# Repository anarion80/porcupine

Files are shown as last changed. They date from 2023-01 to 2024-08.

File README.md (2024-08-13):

# Porcupine 






Porcupine is an autogenerated, ergonomic, split, 36-42 key, wired/wireless, columnar-staggered keyboard. It is designed to fit my needs and my hand, but it can be easily updated thanks to declarative design.
It uses a ProMicro-compatible MCU board and supports both [QMK](https://qmk.fm/) and [ZMK](https://zmk.dev/) firmwares.

It is inspired by:

* [[Ferris] Sweep](https://github.com/davidphilipbarr/Sweep) keyboard
* [rae-dux](https://github.com/andrewjrae/rae-dux) keyboard
* [samoklava](https://github.com/soundmonster/samoklava) and its workflow
* all the work done by [Ben Vallack](https://github.com/benvallack) on his [Youtube channel](https://www.youtube.com/c/BenVallack)

It is fully Open-Source: the KiCad files are released under the solderpad license, version 2.1. The software (scripts/config files) in this repository is released under the GPL.

## :sparkles: Features

* Autogenerated - PCB layout is declared using YAML config files and generated into PCB files using [Ergogen](https://github.com/ergogen/ergogen) tool (migrated to V4).
Use [my fork](https://github.com/anarion80/ergogen) of it for added footprints.
* 3 variants:
  * regular 5x3 column-staggered ortholiner layout with 3 thumb keys (36 keys total)
  * regular 5x3 column-staggered ortholiner layout with 4 thumb keys (38 keys total)
  * regular 6x3 column-staggered ortholiner layout with 4 thumb keys (42 keys total)
* Wired or wireless
* Low-profile (using [Kailh Choc](http://www.kailh.com/en/Products/Ks/CS/) switches)
* Reversible PCB (save cost in production)
* Pro-micro/Elite C/Proton C/[nice!nano](https://nicekeyboards.com/nice-nano/) support
* Hot-Swap support
* SplitKB Tenting puck support.
* uses [KiKit](https://github.com/yaqwsx/KiKit) to render PCB previews (see below)
* uses [KiBot](https://github.com/INTI-CMNB/KiBot) to run DRC, create Gerber and Drill files for production (and Interactive BOM and 3d renders just for fun)

Front/Left | Back/Right
-|-
Porcupine
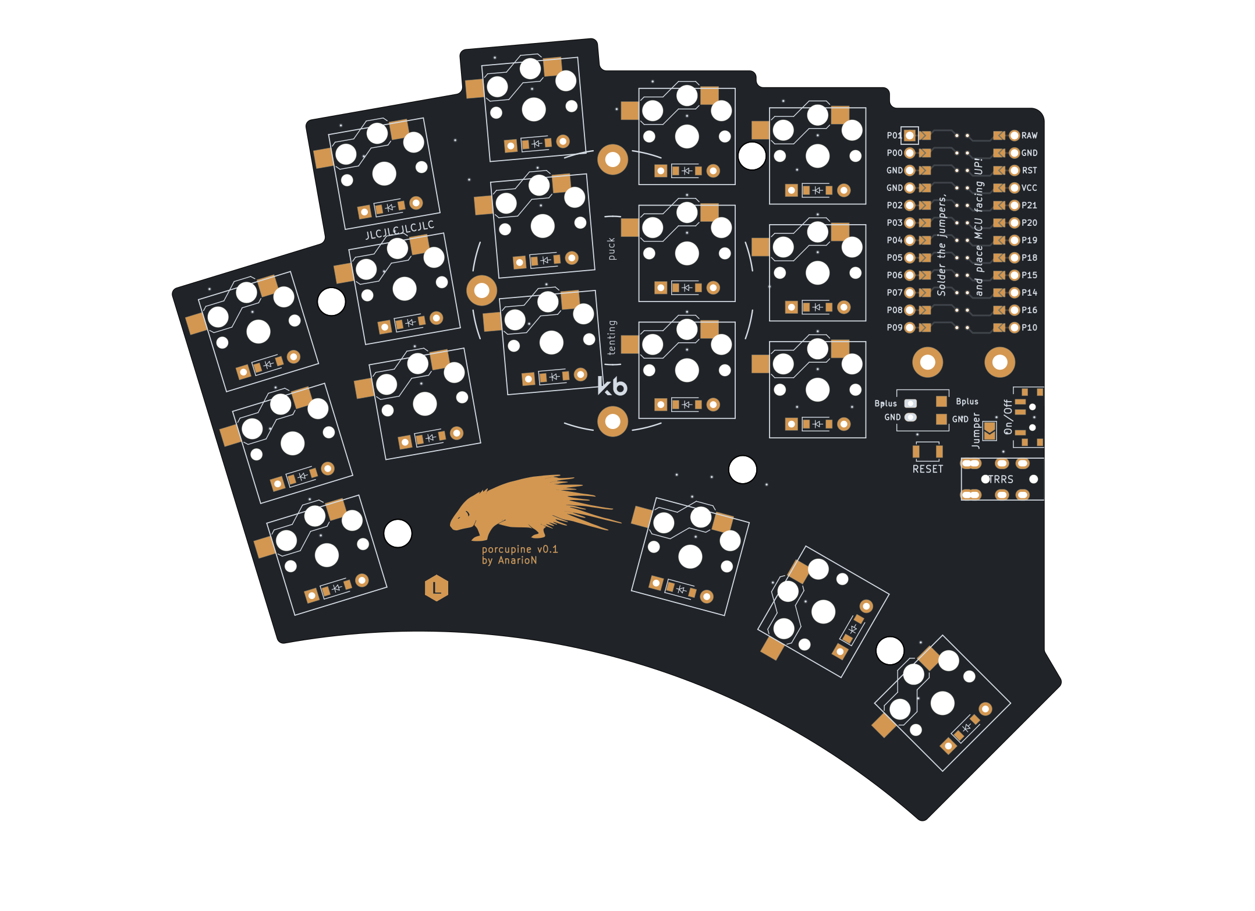
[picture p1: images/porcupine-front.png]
Porcupine Front
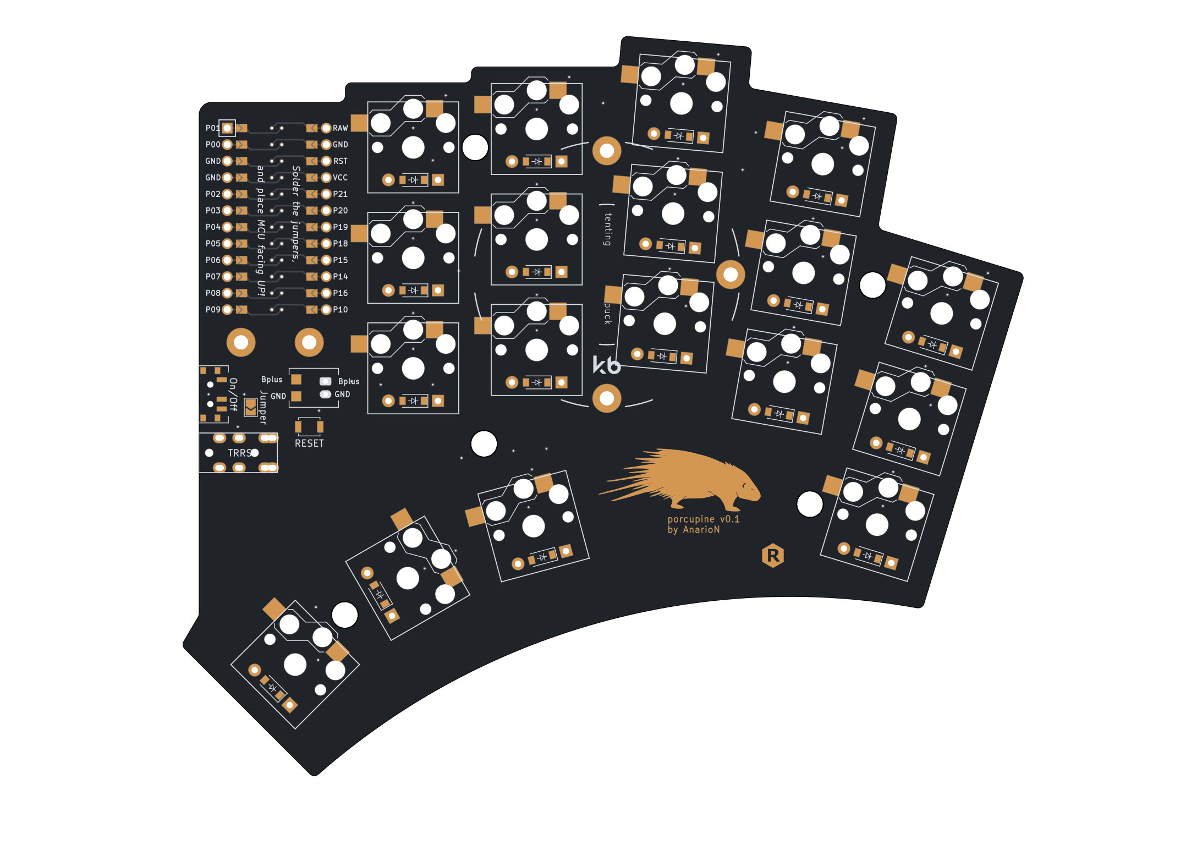
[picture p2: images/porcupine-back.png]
Porcupine Back
 | 
Porcupine 4 thumb keys
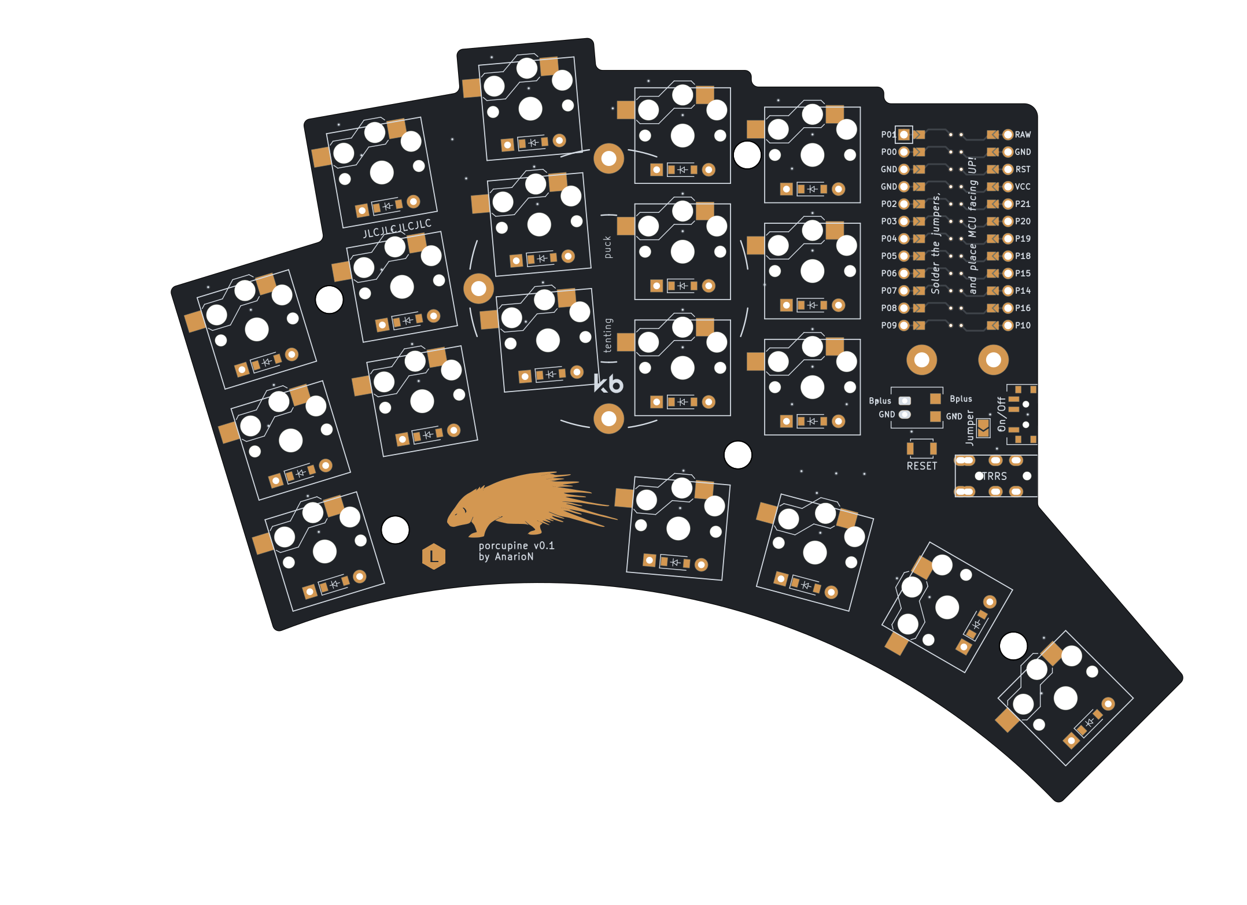
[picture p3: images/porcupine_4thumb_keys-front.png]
Porcupine Front
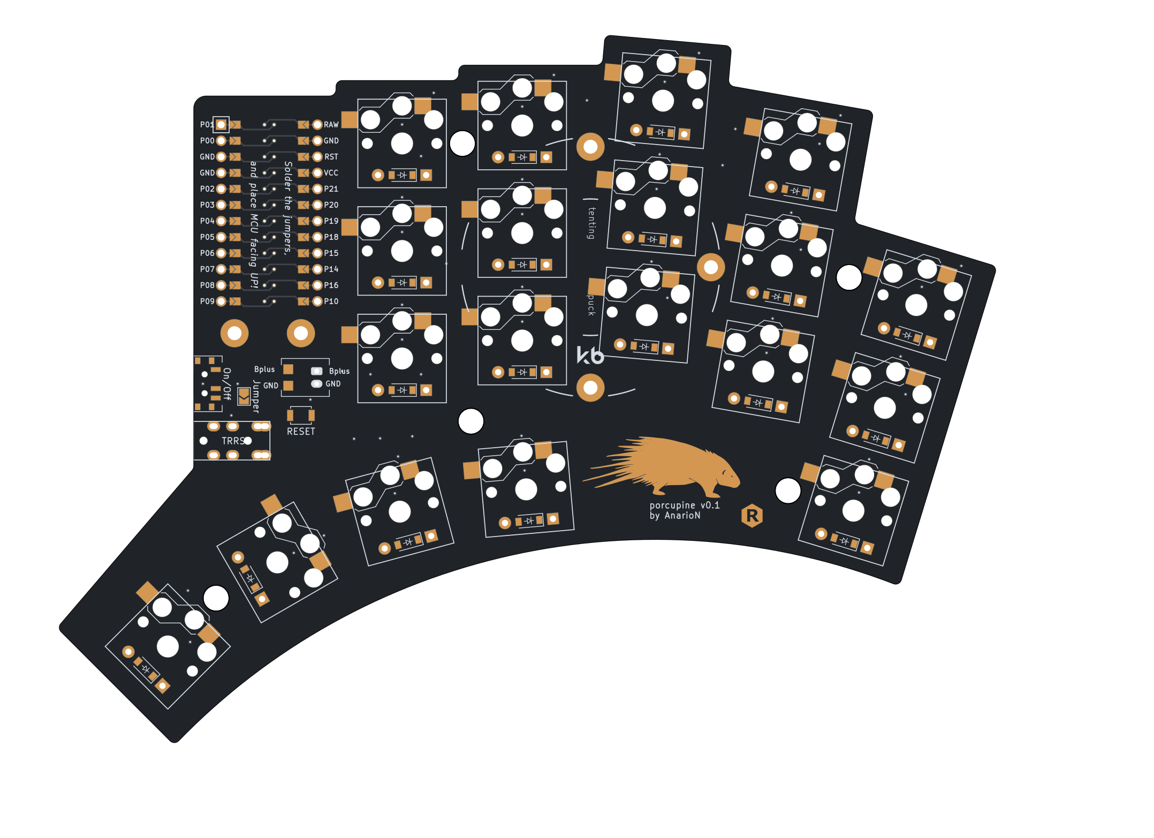
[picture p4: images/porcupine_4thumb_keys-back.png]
Porcupine Back
 | 
Porcupine 3x6
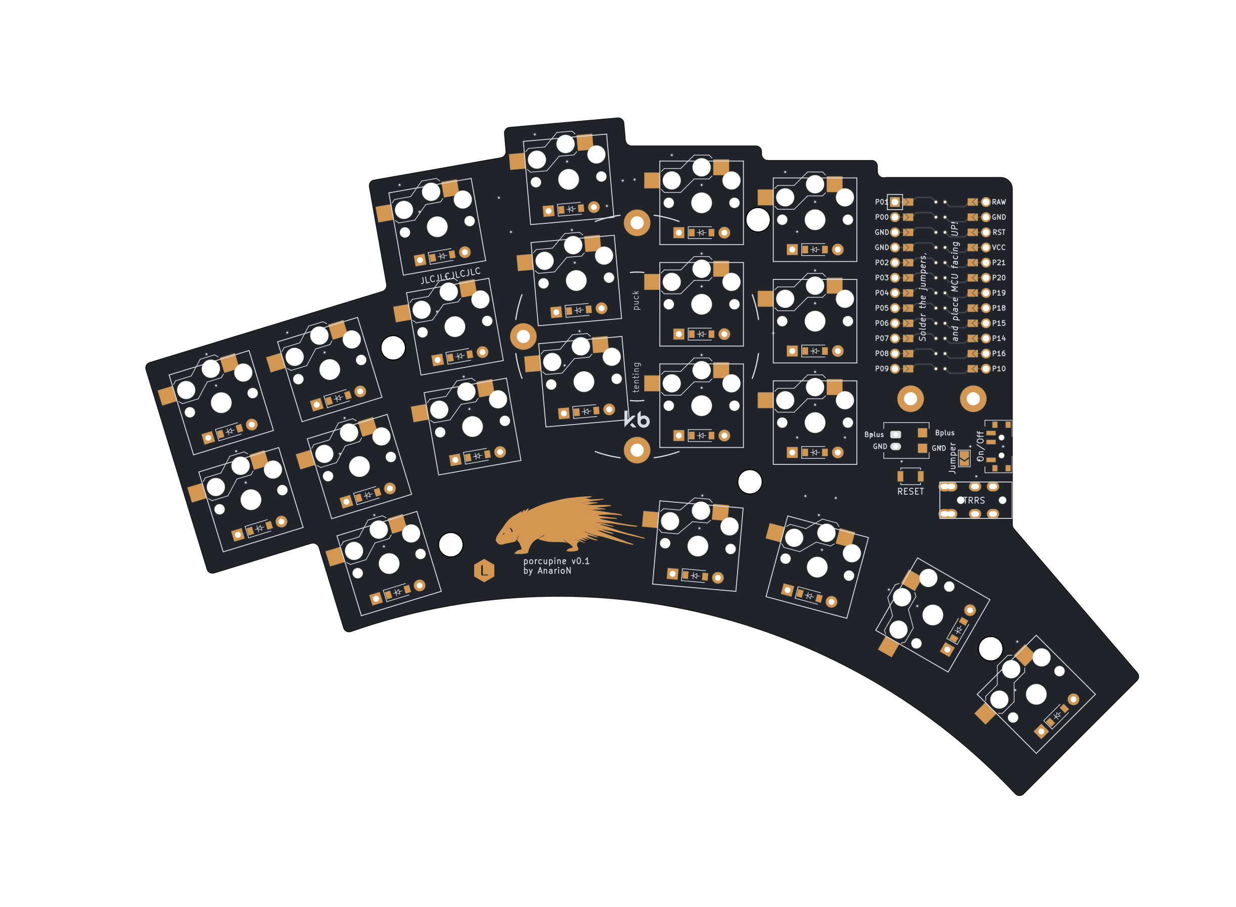
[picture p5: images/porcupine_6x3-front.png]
Porcupine Front
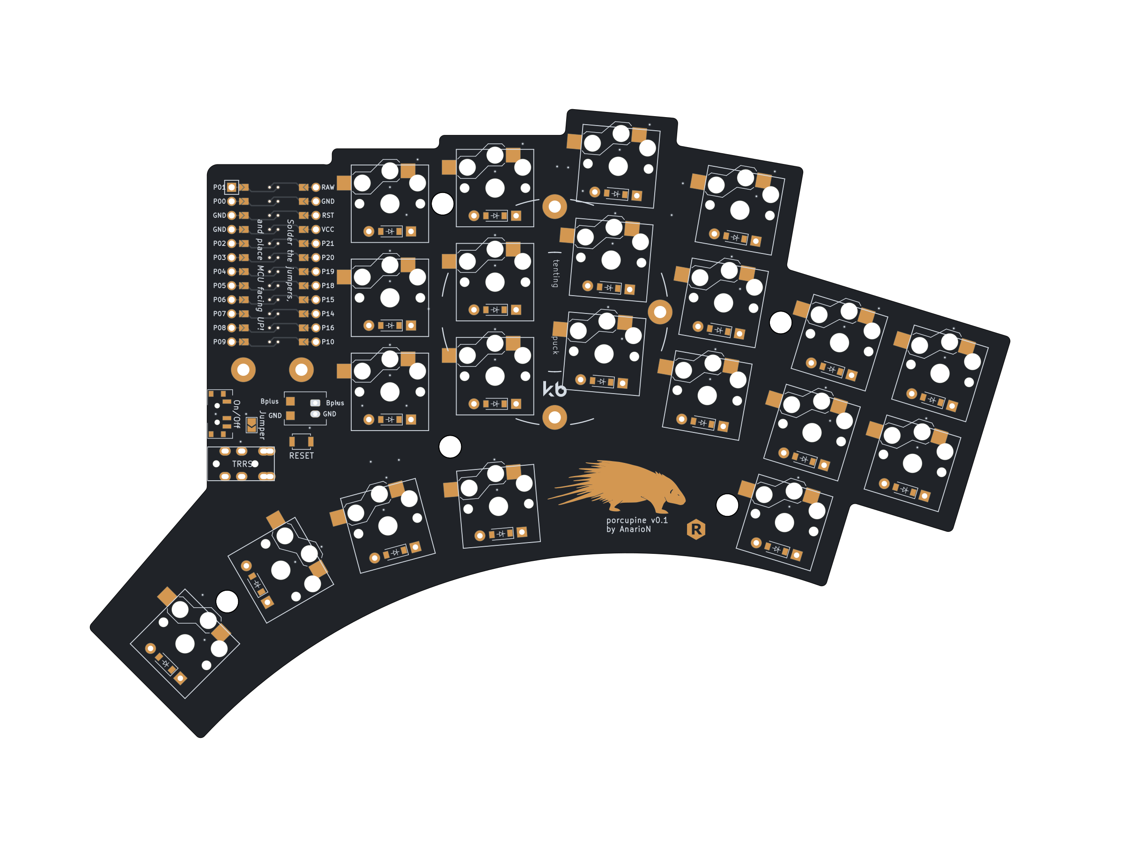
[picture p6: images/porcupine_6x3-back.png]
Porcupine Back
 | 
Prototype boards (generated using Ergogen v3 still):
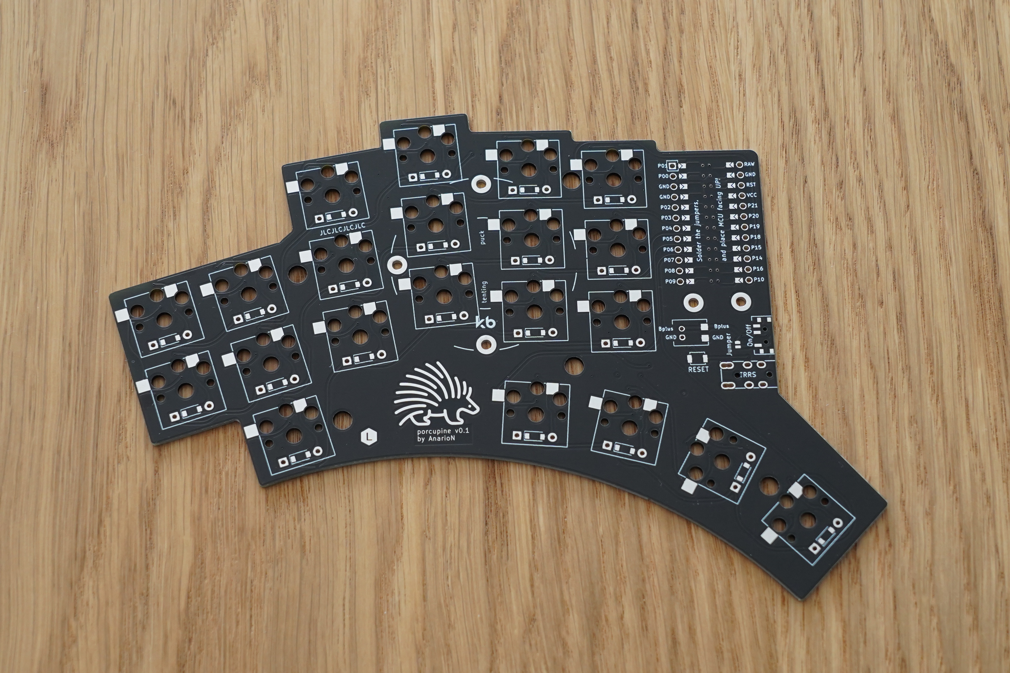
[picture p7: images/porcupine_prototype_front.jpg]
Porcupine Front
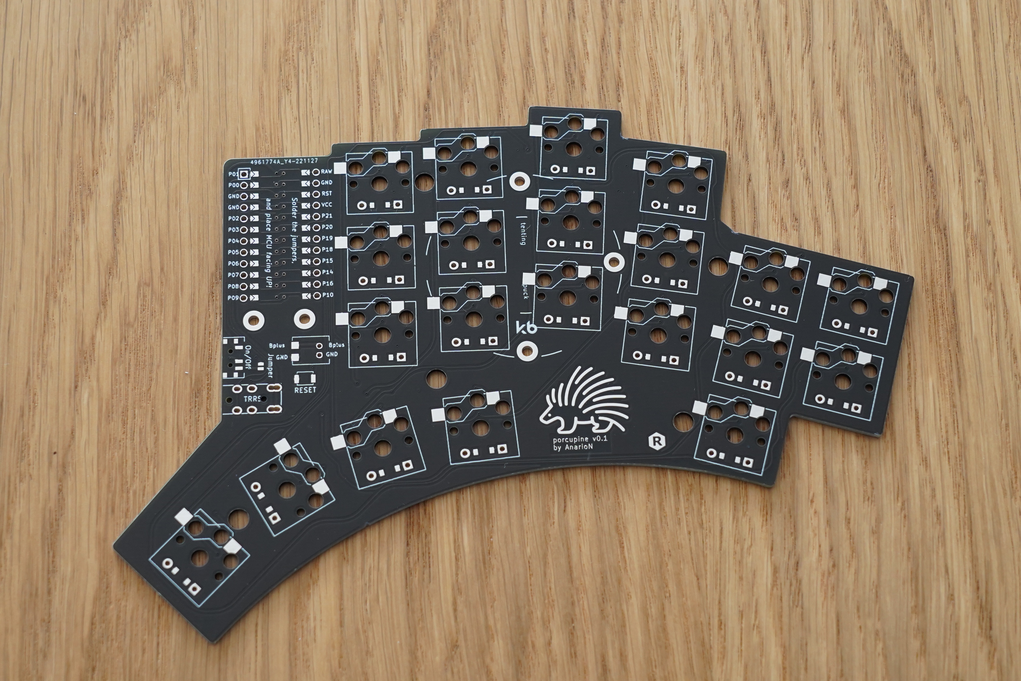
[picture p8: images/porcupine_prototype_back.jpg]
Porcupine Back
 | 
Porcupine working final prototype
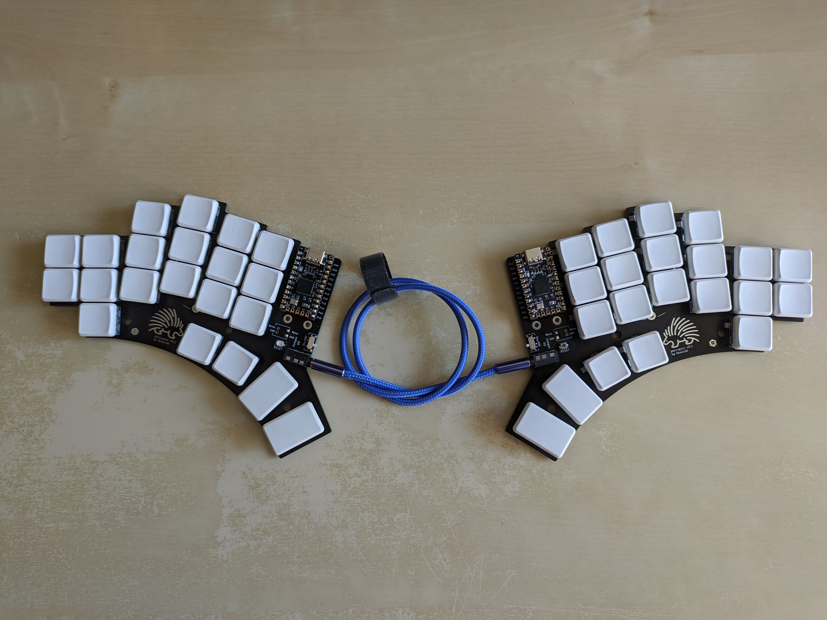
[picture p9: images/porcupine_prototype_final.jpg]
Porcupine working final prototype


## :receipt: Components list

To build and use a Porcupine you will need:

* 1x PCB Kit
* 2x promicro compatible boards or 2 nice!nanos.
* 34-42 Choc V1 Low profile switches
* 34-42 Kailh Choc hot-swap sockets
* 34-42 diodes (SMD or THT)
* 34-42 keycaps
* 2x reset switches (optional; B3U-1000P(M))
* 4x 12x low profile female headers (optional; only if you want the microcontroller socketed)
* 48x Mill Max low profile socket pins (optional; socketed microcontroller; if you are using tht diodes you can use the legs of those diodes)
* Some little rubber feet/bumpers
* 2x power (On/Off) switches (optional; MSK 12C02)
* JST PH battery connector (wireless build; S2B-PH-K)
* Li-Po 110mAh battery (wireless build; 301230)
* 1x TRRS (not TRS!) cable (wired build only)
* 2x TRRS Jack [PJ-320A] (wired build only)
* 1 USB Cable (wired build; depends on your micro-controller choice)

## :construction_worker: Build Guide

Manually-routed PCBs for each variant are included in the `output` folder, so if they are fine for you, you can just take them directly, have them produced and then build.

For step-by-step instructions on assembling the keyboard, see the [Porcupine build guide](build_guide.md).

## :keyboard: Firmware/keymaps

[QMK firmware and keymaps](https://github.com/anarion80/porcupine_qmk) - confirmed working with the prototype boards! :tada:

[ZMK firmware and keymaps](https://github.com/anarion80/zmk-config-porcupine) - confirmed working now as well! :tada:

## :pencil2: How to use/update/modify

If you would like to modify this:

* fork it
* (optionally, to see the 3d view of generated PCB in KiCad)
  * copy 3d models from `3dmodels/ergogen` folder into your KiCad's installation `${KICAD6_3RD_PARTY}/3dmodels/ergogen/` folder[^1].
* change `input/porcupine*.yaml` to your liking
* commit to Github

The associated Github Workflow action will then generate the PCB, 2D Images of the board and a whole KiBot package with Gerber/Drill files, Interactive Bom, images and renders.
The files will be available as Workflow Action artifacts.

:warning: The boards will come out unrouted! But if you add a manually routed board to `output/[board_name]/pcbs/` folder, the Workflow will pick it up and generate everything for it as well.

If you would rather do all that locally, then:

* install Ergogen: `npm install`
* install Docker
* generate PCBs: `npm run gen_pcb`
* generate images: `npm run gen_images`
* generate Kibot package: `npm run gen_kibot`

Further:

* route the board manually in KiCad
* produce (for eample in [JLCPCB](https://jlcpcb.com/) or [PCBWay](https://www.pcbway.com/))
* build
* load firmware
* use it!

## :warning: Important Notes

* Kicad files are 6.0, so unfortunately not backwards compatible.
* If you're going for wired version or just want to skip out on the power switch, you need to solder the Jumper.
* Manually-routed boards are included, but there is no autorouting for generated boards.
* You need to have Docker installed to use `npm run gen_images` or `npm run gen_kibot` to generate pcb images and Kibot bundle.

## :hammer: TODO

* [ ] a variant with MX switches
* [x] automation of DRC/BOM/Gerber creation/validation with Github workflow
* [ ] proper 3d-printable cases
* [ ] LED support

## :page_facing_up: Disclaimer

The author(s) waive(s) responsibility for any damage or regulatory violations caused by using this hardware and software (see license). Please consult your local regulations around radio frequencies and what's allowed for DIY projects in your country.

Porcupine logo by [@migorzka](https://www.instagram.com/migorzka/)

[^1]: The models are bundled here in the repository, but they are taken from [KiCad](https://www.kicad.org/) directly, from [keyswitch-kicad-library](https://github.com/perigoso/keyswitch-kicad-library) or are created by me.

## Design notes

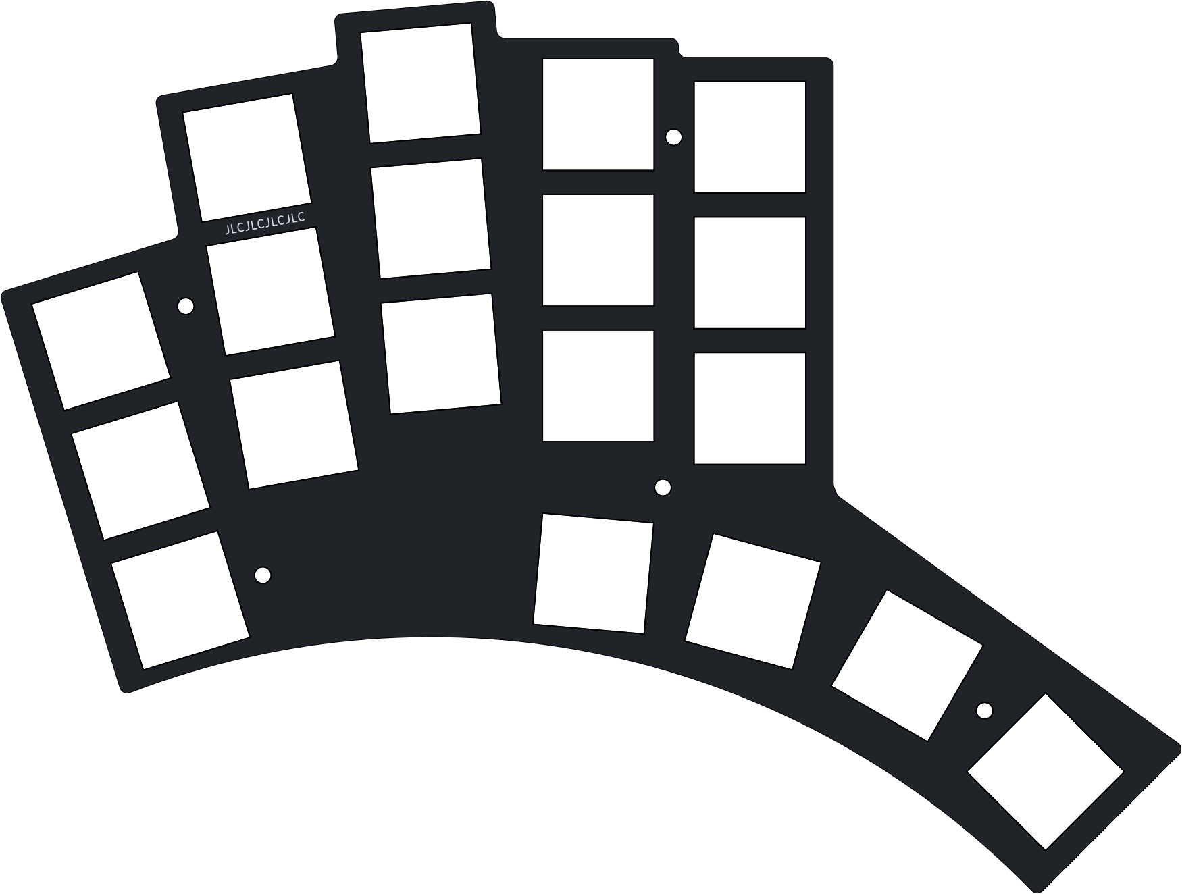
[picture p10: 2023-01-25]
images/porcupine_4thumb_keys_top_plate-front.png

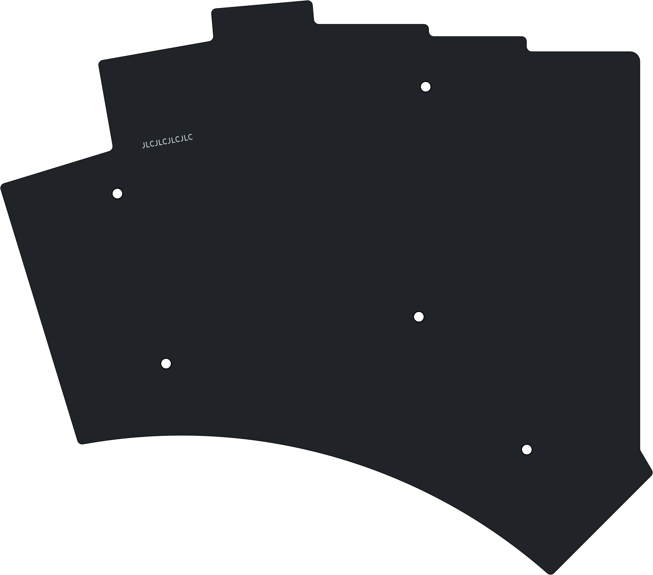
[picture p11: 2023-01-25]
images/porcupine_bottom_plate-front.png

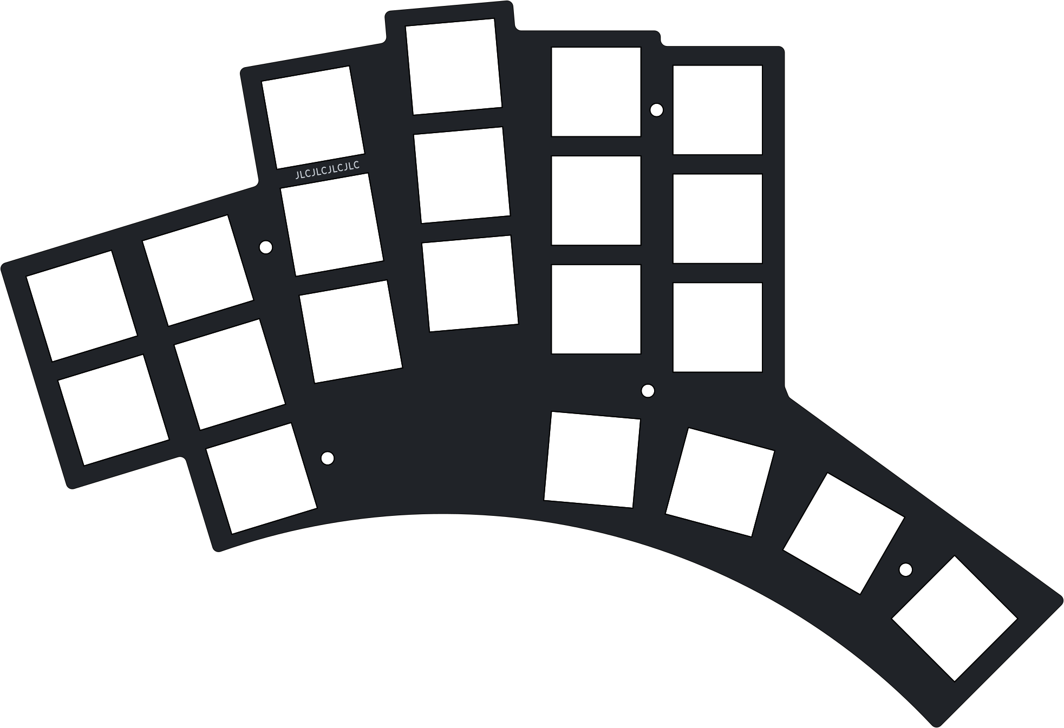
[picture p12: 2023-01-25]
images/porcupine_6x3_top_plate-front.png

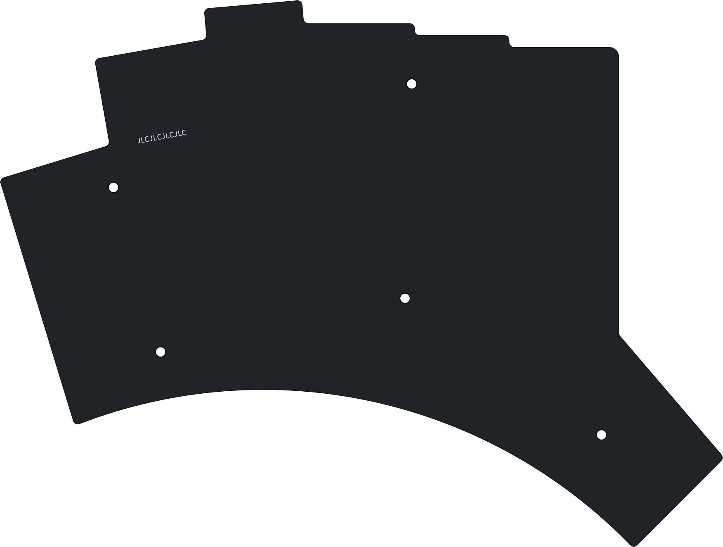
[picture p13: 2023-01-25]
images/porcupine_4thumb_keys_bottom_plate-front.png

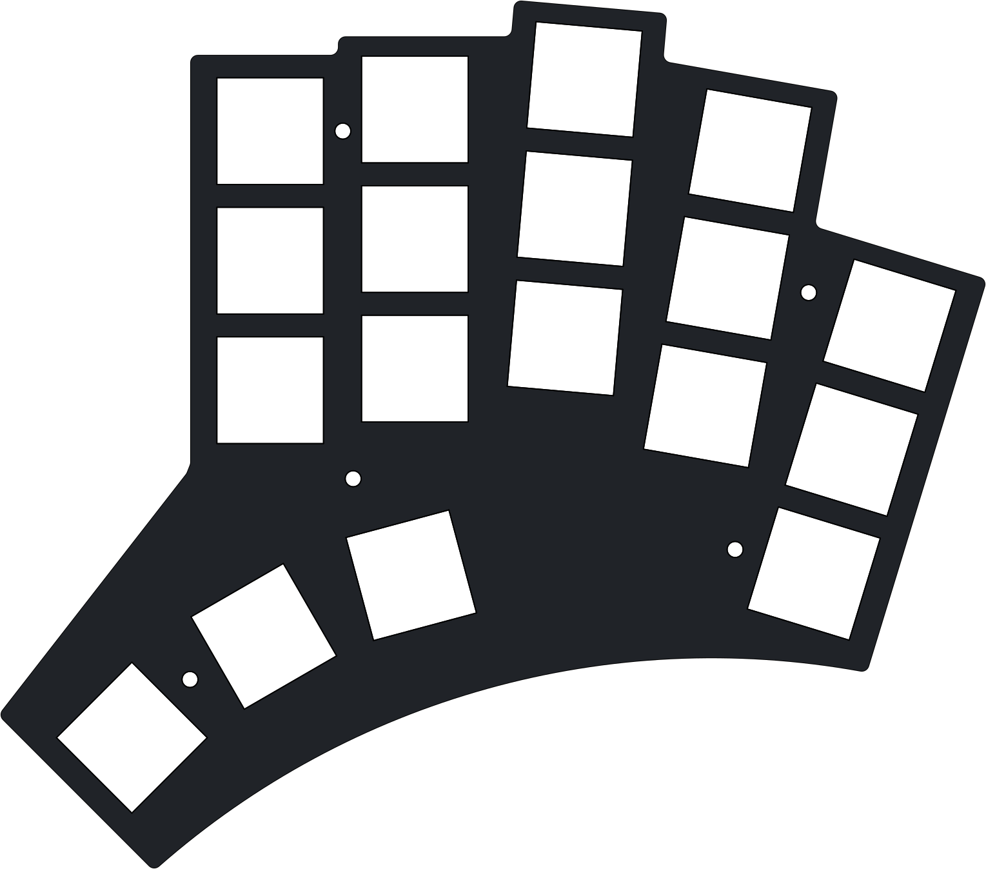
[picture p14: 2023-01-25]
images/porcupine_top_plate-back.png

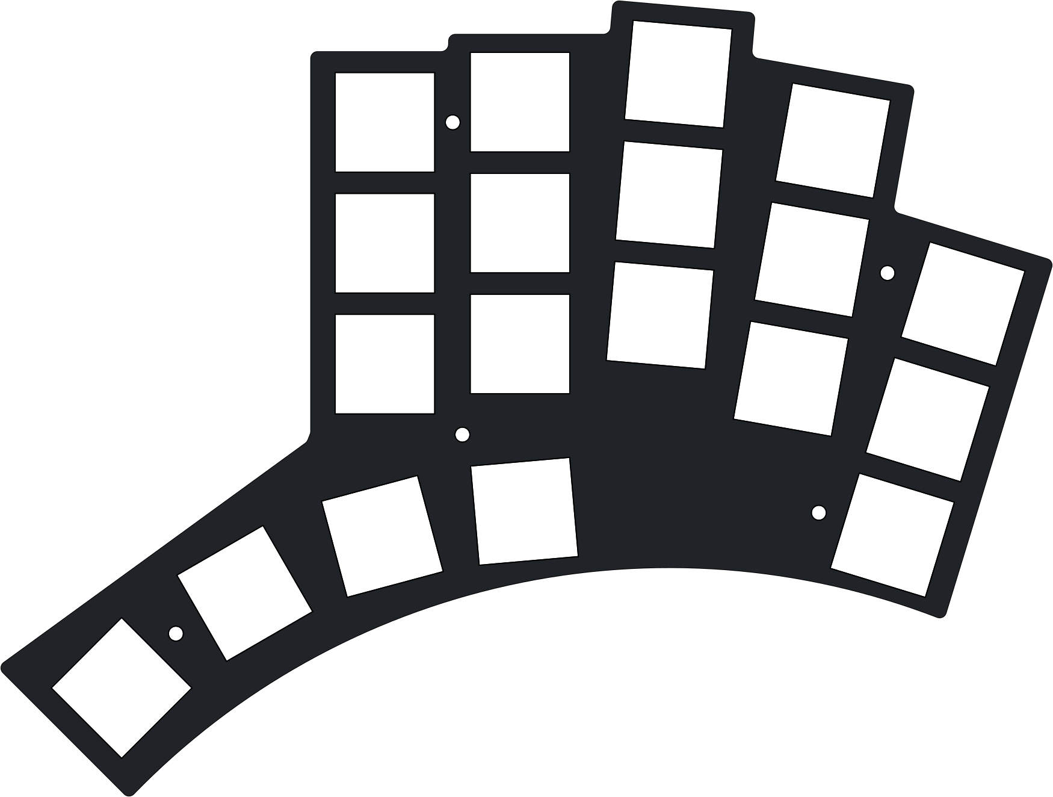
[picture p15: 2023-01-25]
images/porcupine_4thumb_keys_top_plate-back.png

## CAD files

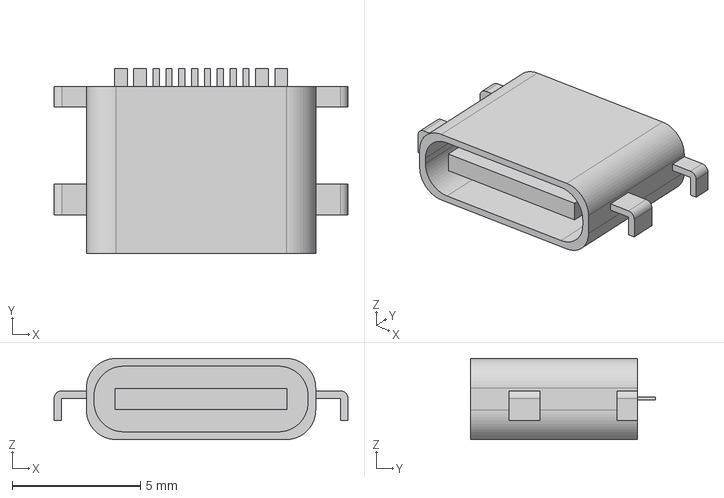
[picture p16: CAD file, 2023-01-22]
3dmodels/ergogen/USB-C-C168688.step
11.5 x 7.20 x 3.16 mm

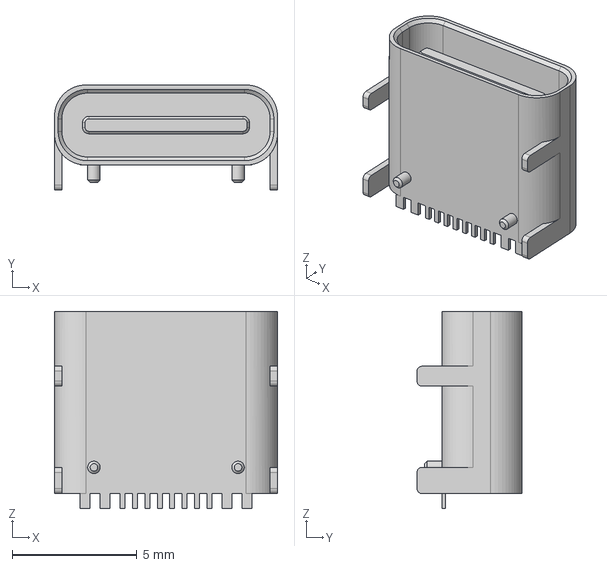
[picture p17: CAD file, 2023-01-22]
3dmodels/ergogen/HRO TYPE-C-31-M-12.step
8.94 x 4.21 x 7.90 mm

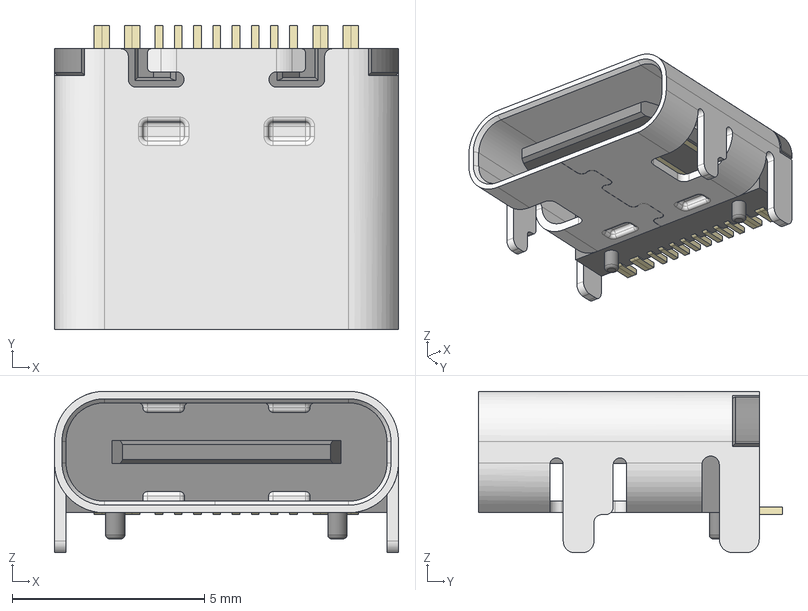
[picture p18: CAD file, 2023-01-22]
3dmodels/ergogen/CON_TYPE-C-31-M-12.step
8.95 x 7.90 x 4.20 mm

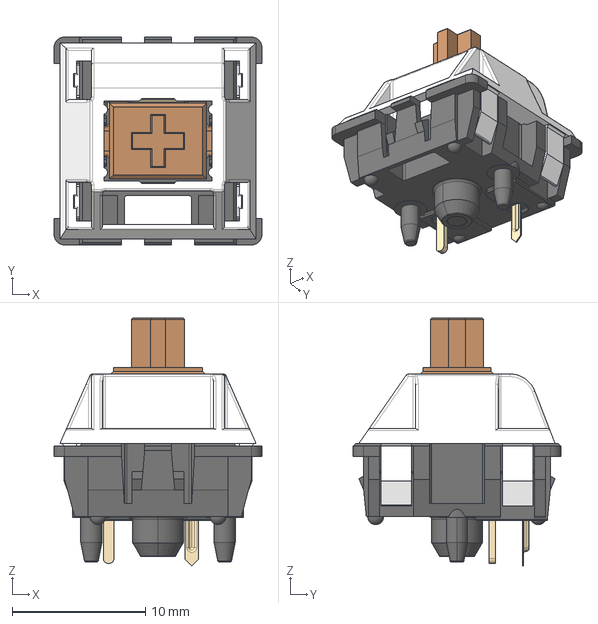
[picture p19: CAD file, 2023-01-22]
3dmodels/ergogen/SW_Cherry_MX_PCB.stp
15.6 x 15.6 x 18.6 mm

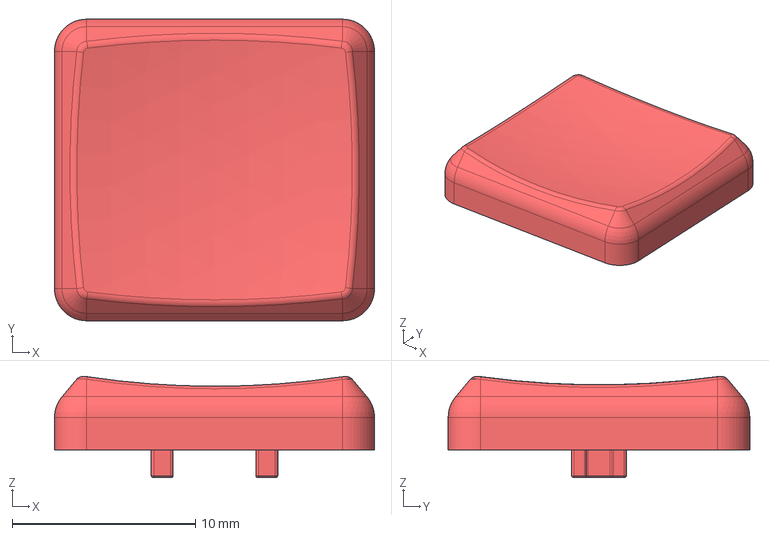
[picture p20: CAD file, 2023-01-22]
3dmodels/ergogen/MBK_1u.step
17.4 x 16.4 x 5.52 mm

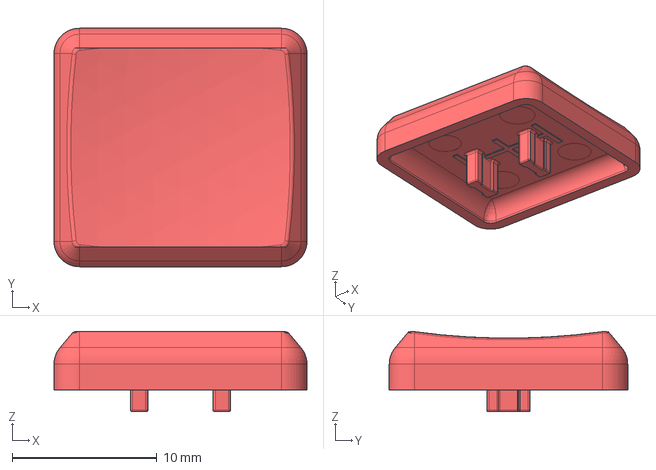
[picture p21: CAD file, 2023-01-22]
3dmodels/ergogen/MBK_Keycap_-_1u_Homing.step
17.5 x 16.4 x 5.54 mm

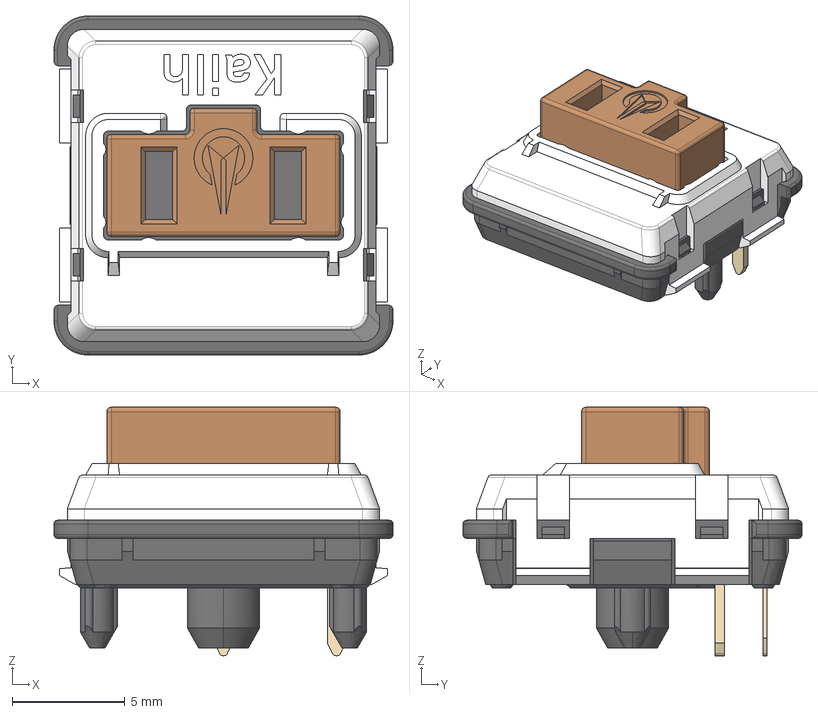
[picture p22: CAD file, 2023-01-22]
3dmodels/ergogen/SW_Kailh_Choc_V1.stp
15.0 x 15.0 x 11.0 mm

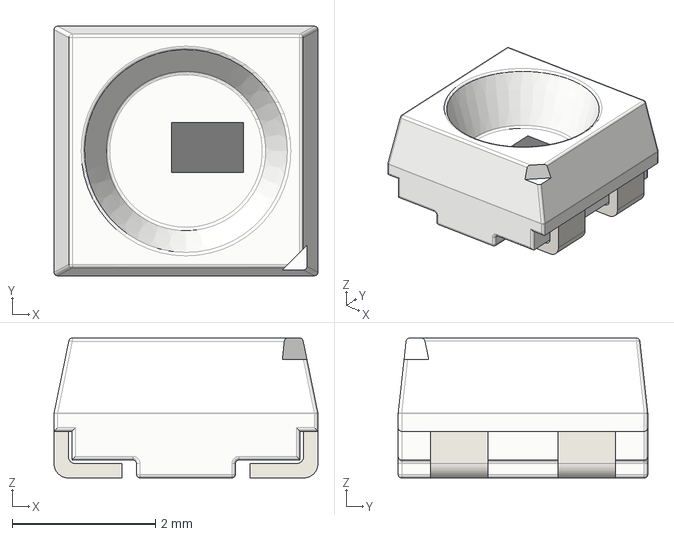
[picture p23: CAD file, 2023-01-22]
3dmodels/ergogen/LED_WS2812B-MINI.step
3.68 x 3.48 x 1.95 mm

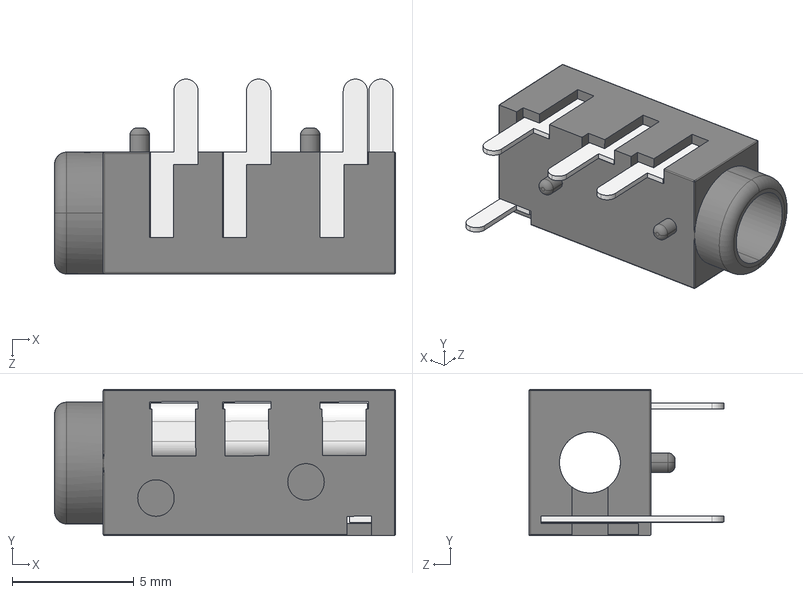
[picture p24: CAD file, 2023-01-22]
3dmodels/ergogen/PJ320A.STEP
14.0 x 6.00 x 8.00 mm
PJ320A
PJ320A-Pin x 3
PJ320A-Pin-B

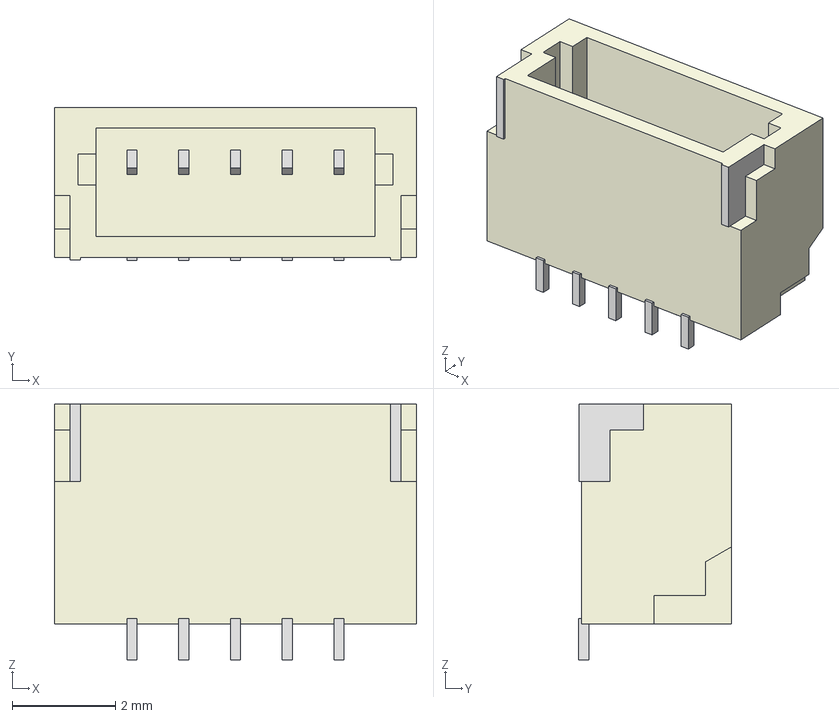
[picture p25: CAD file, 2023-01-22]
3dmodels/ergogen/CON_SM05B-SRSS-TB.step
7.00 x 2.96 x 4.95 mm

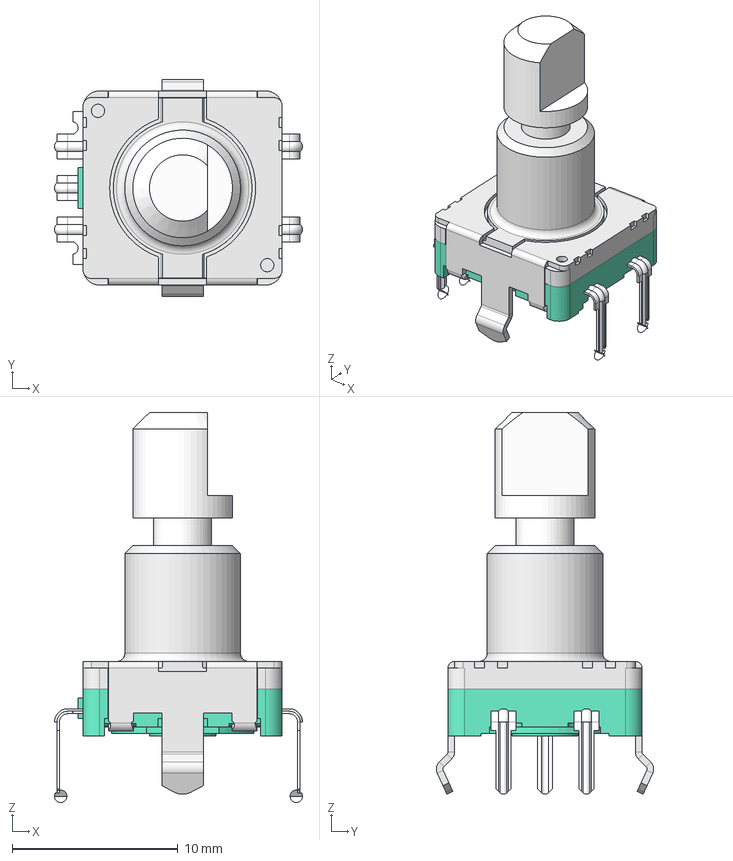
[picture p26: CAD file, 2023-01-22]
3dmodels/ergogen/ROT_EC11N.step
14.9 x 13.1 x 23.5 mm

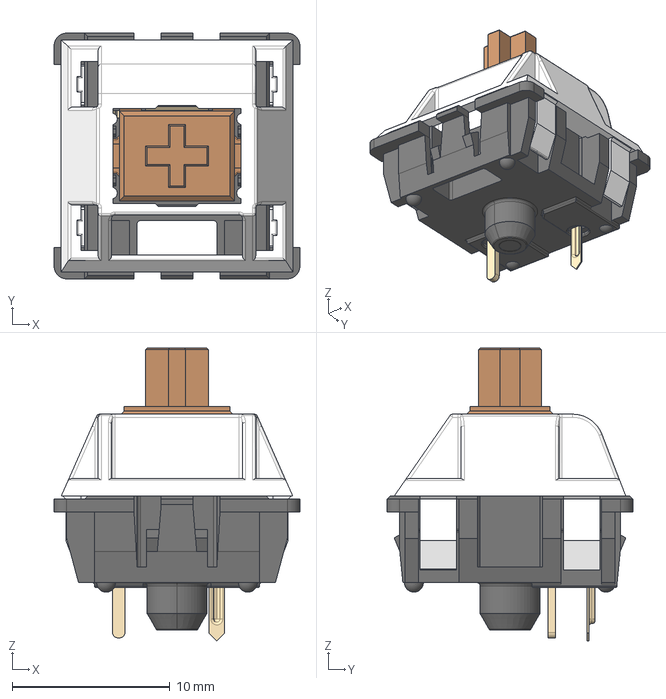
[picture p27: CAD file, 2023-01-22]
3dmodels/ergogen/SW_Cherry_MX_Plate.stp
15.6 x 15.6 x 18.6 mm

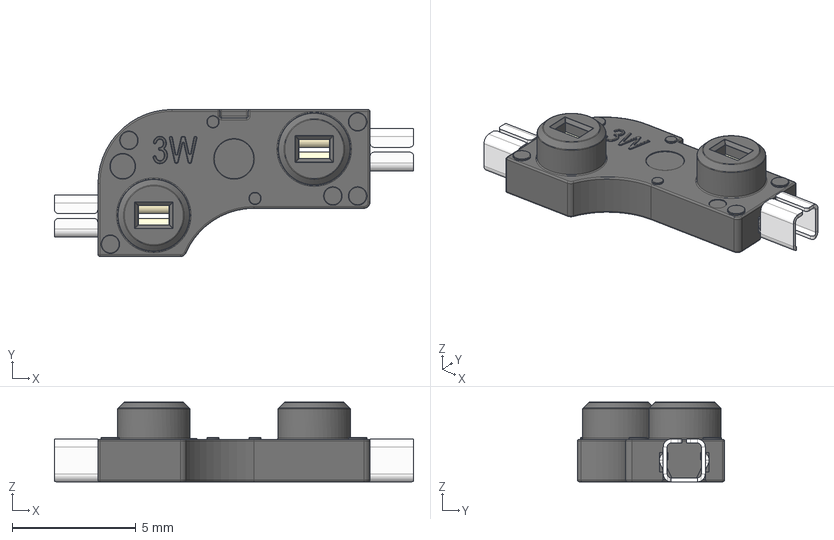
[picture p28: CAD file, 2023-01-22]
3dmodels/ergogen/SW_Hotswap_Kailh.stp
14.5 x 5.95 x 3.22 mm

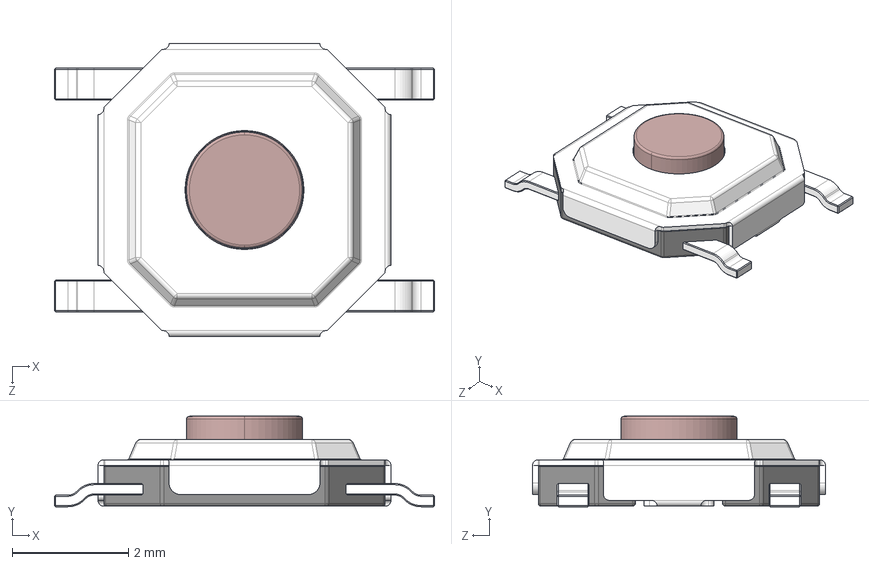
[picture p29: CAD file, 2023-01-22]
3dmodels/ergogen/Switch_SKQG.step
6.55 x 1.56 x 5.05 mm
bottom part_ﾄｬﾈﾏｨｨ_
bottom pin_ﾄｬﾈﾏｨｨ_
top shield_ﾄｬﾈﾏｨｨ_
copper button_ﾄｬﾈﾏｨｨ_
shrapnel_默认è_

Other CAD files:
3dmodels/ergogen/CON_SM04B-SRSS-TB.step
3dmodels/ergogen/MBK_Keycap_-_1.5u.step
3dmodels/ergogen/CON_SM08B-SRSS-TB.step
3dmodels/ergogen/CON_SM02B-SRSS-TB.step
3dmodels/ergogen/CON_Kailh_HS.step
3dmodels/ergogen/CON_SM06B-SRSS-TB.step
3dmodels/ergogen/D_SOD-123.step
3dmodels/ergogen/Fuse_1206.step
3dmodels/ergogen/LED_SK6812MINI-E.step
3dmodels/ergogen/MBK_Keycap_-_1u.step
3dmodels/ergogen/MBK_Keycap_-_2u.step
3dmodels/ergogen/PG1350-socket.STEP
3dmodels/ergogen/ROT_EC11E.step
3dmodels/ergogen/S2B-PH-K-S.step
3dmodels/ergogen/Stabilizer_Cherry_MX_2u.stp
3dmodels/ergogen/Stabilizer_Cherry_MX_3u.stp
3dmodels/ergogen/Stabilizer_Cherry_MX_6_25u.stp
3dmodels/ergogen/Stabilizer_Cherry_MX_6u.stp
3dmodels/ergogen/Stabilizer_Cherry_MX_7u.stp
3dmodels/ergogen/Stabilizer_Cherry_MX_8u.stp
3dmodels/ergogen/Switch_ESP3020.step

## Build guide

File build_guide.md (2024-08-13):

# Porcupine keyboard build guide

This build guide assumes a basic understanding of soldering, if this is your
first time soldering, first watch a tutorial on the basics of soldering. I
recommend [the tutorial by greatscott](https://youtu.be/VxMV6wGS3NY).

## Parts

* 1x PCB Kit
* 2x promicro compatible boards or 2 nice!nanos.
* 34-42 Choc V1 Low profile switches
* 34-42 Kailh Choc hot-swap sockets
* 34-42 diodes (SMD or THT) 
* 34-42 keycaps
* 2x reset switches (optional; B3U-1000P(M))
* 4x 12x low profile female headers (optional; only if you want the microcontroller socketed)
* 48x Mill Max low profile socket pins (optional; socketed microcontroller; if you are using tht diodes you can use the legs of those diodes)
* Some little rubber feet/bumpers
* 2x power (On/Off) switches (optional; MSK 12C02)
* JST PH battery connector (wireless build; S2B-PH-K)
* Li-Po 110mAh battery (wireless build; 301230)
* 1x TRRS (not TRS!) cable (wired build only)
* 2x TRRS Jack [PJ-320A] (wired build only)
* 1 USB Cable (wired build; depends on your micro-controller choice)

## Getting the pcb printed

There are a few services where you can print pcb, I used JLCPCB but others will
work too.

First grab the kicad file for the version you want to build located in 
`output/[version]/pcbs/[version]_routed.kicad_pcb`

Then export the gerber files using 
[this guide](https://jlcpcb.com/help/article/362-how-to-generate-gerber-and-drill-files-in-kicad-7).

When ordering the from JLCPCB the defaults are fine, the only thing I changed 
was the color to black.

The pcb design is reversible, so both sides of the keyboard use the
same pcb. So no need to order two separate pcb's.

## Build Guide

The build process is straight forward. Just make sure to double check everything
before soldering. Getting this wrong will mean desoldering which is a pain and
can result in lifted pads if you aren’t careful. Better to get it right and not
have to deal with that.

The pcb is reversible, so keep in mind that everything you solder on one side
should be on the other side on the other pcb.

Note: some of the pictures were taken from build guides from different
keyboards so don't be confused if things look a bit different.

1. Solder the hotswap sockets to the back of the pcbs.

The sockets should be soldered on the back side of the pcb. Simply lay the pcb
down an solder the hotswap socket lying down like this:

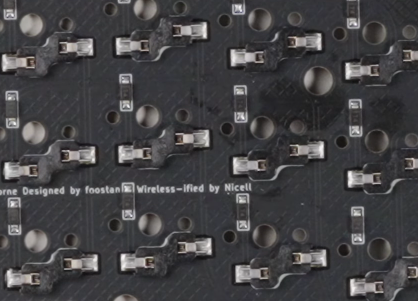
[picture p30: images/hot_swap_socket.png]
Hotswap socket


2. Solder the diodes on the same side as the hotswap sockets

I used 1n4148 SOD123 smd diodes, through hole diodes should also work fine. I
recommend the smd variant because of the lower profile. The easiest way to
solder a smd diode is to first put a little bit of solder on the on
pad, than heat up that pat and push the diode into the pad. First take away the
soldering iron, then the tweezer. A demonstration of this technique can be
viewed [in this youtube video](https://youtu.be/vzDTdLaAzXc?si=NDmReE-nNHSbSBwx&t=499).

For the through hole variant make sure to cut off the legs close to the board
otherwise there might not be enough space for the switches.

Make sure the line on the diode matches the line on the pcb.

3. (Optional) Solder the reset button to the pcb.

A similar technique to the diodes can be used.

4. (Wireless build) Solder on the jst power connector. 

A useful tip for these and for the JST connectors is to use some masking tape
to hold them in place while you’re soldering. With the JST connectors, it’s
important to place them in the right through-holes. Make sure that the red cord
goes to Bplus and the black cord to GND. 

5. Solder on the power switches, or solder the jumper.

If you are not using the on/off switch solder, the jumper next to the switch.

The sliding switches have 7 small pads so they are a little more difficult to
solder than the hotswap sockets. Take your time and reduce the heat of your
soldering iron. It has two pins that fit into holes in the PCBs which should
help keep them in place.

6. (Wired build) Solder the trrs jack

Use tape to hold the component in place.

7. Solder the jumpers

Because the pcb is reversible we need to solder jumpers. Solder on the side
with the switches and microcontroller, so the opposite side of the hot swap
sockets and diodes.

8. Break the female machined pin headers into four rows of 12
9. Solder the pin headers to the front of each PCB
10. Insert the mill-max pins into the pin headers
11. Put the microcontrollers in position and solder them to the mill-max pins
(they should be facing up)

The last step is socketing the microcontrollers. If you’ve never done this
before, the splitkb.com docs have a good guide with pictures. Break off four
rows of 12 of the female machined pin headers and solder them to the front of
each PCB. Again, masking tape may come in handy. Once that’s done, insert the
mill-max pins into the sockets and then put the microcontrollers into place.
Make sure the left microcontroller should be flipped so the flat side (the
back) is facing upwards. Then, solder the pins to the controllers. Be careful,
take your time and reduce the heat of your soldering iron.

Make sure it is the pins all line up correctly, by checking if all the GND pins
match the labels on the pcb.

12. (Wireless build) Lift the microcontrollers from the sockets, position the batteries between the pin headers and reseat the microcontrollers on top of the batteries
13. Insert the switches into the sockets, making sure not to bend any pins.
14. Push the keycaps into the switches.

## Compiling and flashing using qmk

First install and setup qmk using this [guide](https://docs.qmk.fm/newbs_getting_started).

Then navigate to the keyboards directory:

```
cd qmk_firmware/keyboards/
```

Then clone and rename the qmk repo:

```
git clone https://github.com/anarion80/porcupine_qmk
mv porcupine_qmk porcupine
```

Then you can compile a chosen keymap. While compiling you will see some errors
related to the layout, these can be ignored.

```
qmk compile -kb porcupine -km default
qmk compile -kb porcupine -km default_5x3_4
qmk compile -kb porcupine -km default_6x3_4
```

By default it compiles for the elite c, if you are using another board it can
be converted using the convert to flag. In this case it is compiled for a
microcontroller using the rp2040 chip. For more info on converting read the 
[documentation](https://docs.qmk.fm/feature_converters).

```
qmk compile -kb porcupine -km default -e CONVERT_TO=rp2040_ce
```

Flashing depends on what microcontroller was used, read the [documentation](https://docs.qmk.fm/flashing).

## Acknowledgement
This build guide was adapted from the [rae-dux build guide](https://www.tzcl.me/posts/rae-dux/).

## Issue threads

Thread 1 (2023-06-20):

Pinout compatibility question.

shroomist, 2023-06-20:
Excited to see this project.
I'm currently on corne/zmk/n!n2 with miryoku layout.
Wondering about the status for zmk, on readme it's still not confirmed.

What is the pinout letter routing like?
can I simply replace my corne with porcupine in my layout config or the switch is more involved?
is the pinout similar to any of zmk supported boards?

anarion80, 2023-06-21:
Hello. I haven't yet started ZMK config for this... Kinda waiting to properly solder battery/battery connector, but mostly testing my Miryoku-like keymap in QMK plus the keyboard itself (and in here it slowly becomes obvious that pinky stagger is too big and that miryoku is not perfect for fast typing...)

For the pinout, if you're asking if you can use the same shield as corne for ZMK, then without checking in detail I would say no, it's not a drop-in replacement due to different number of thumb keys and outer pinky keys. So that needs to be checked properly.

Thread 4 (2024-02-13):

Kicad DRC gives me 357 hole clearence violations.

mrkskk, 2024-02-13:
Runnng DRC before generating gerbers gives me a lot of errors.
So im questioning whether the PCB will still work?

anarion80, 2024-02-13:
Yes, this is because the reversible, hot-swap choc switch footprint has the hot-swap pads overlapping a bit with the holes for switch. You should downgrade that error to violation. Anyway, this is ok and the PCB will work.

mrkskk, 2024-02-14:
Sounds good. sending it unedited to JLC now 👍

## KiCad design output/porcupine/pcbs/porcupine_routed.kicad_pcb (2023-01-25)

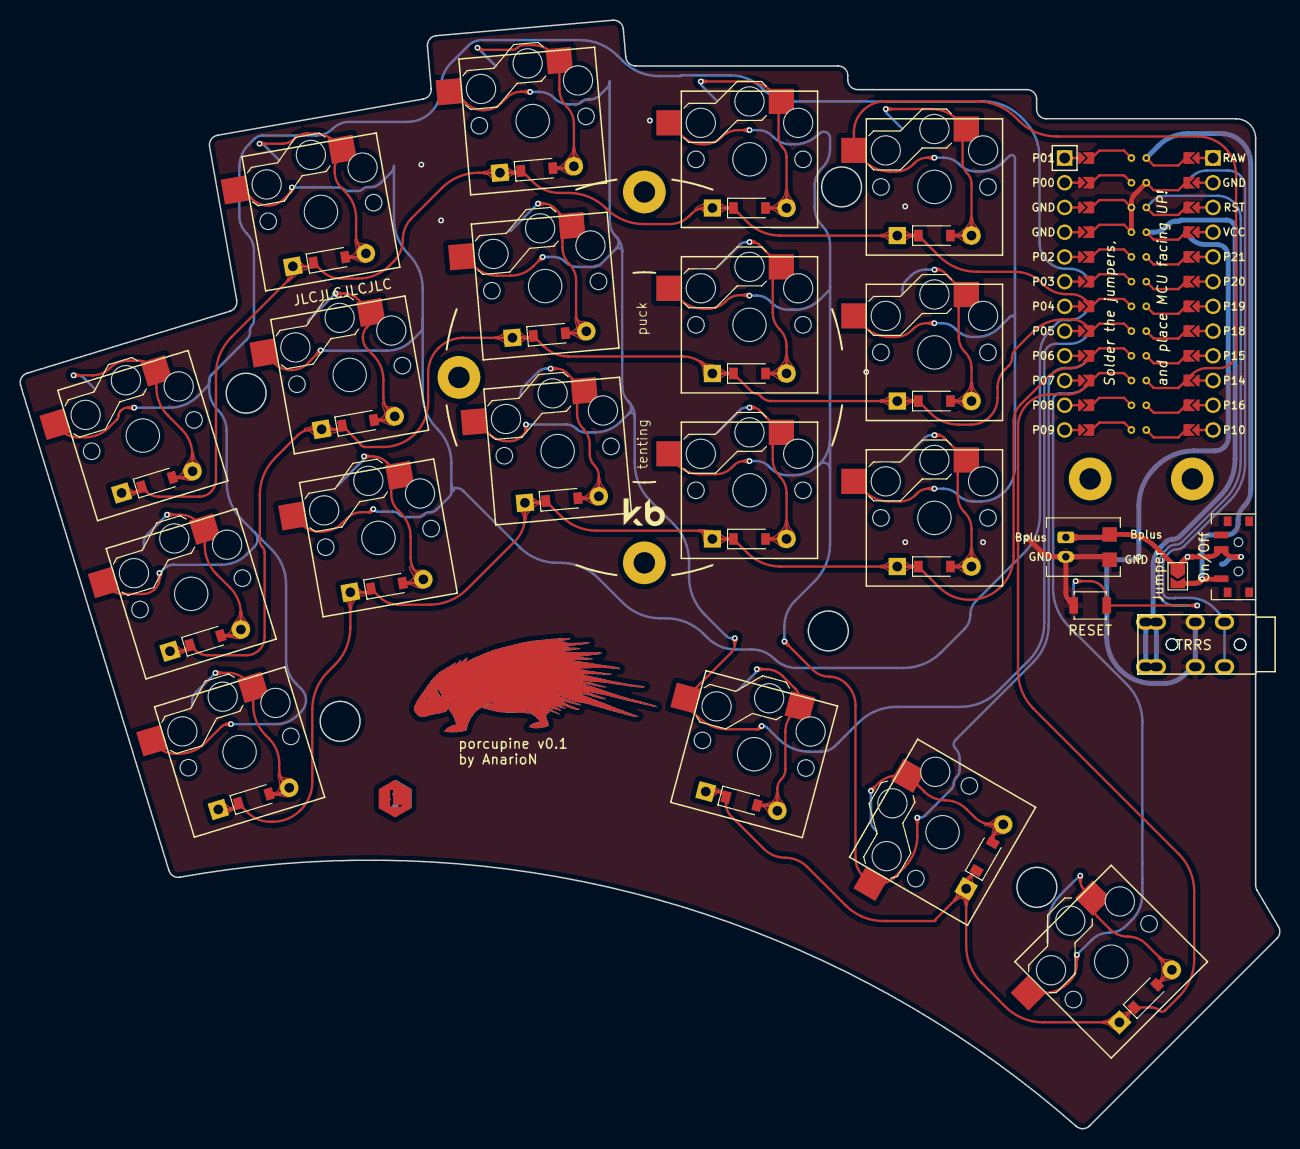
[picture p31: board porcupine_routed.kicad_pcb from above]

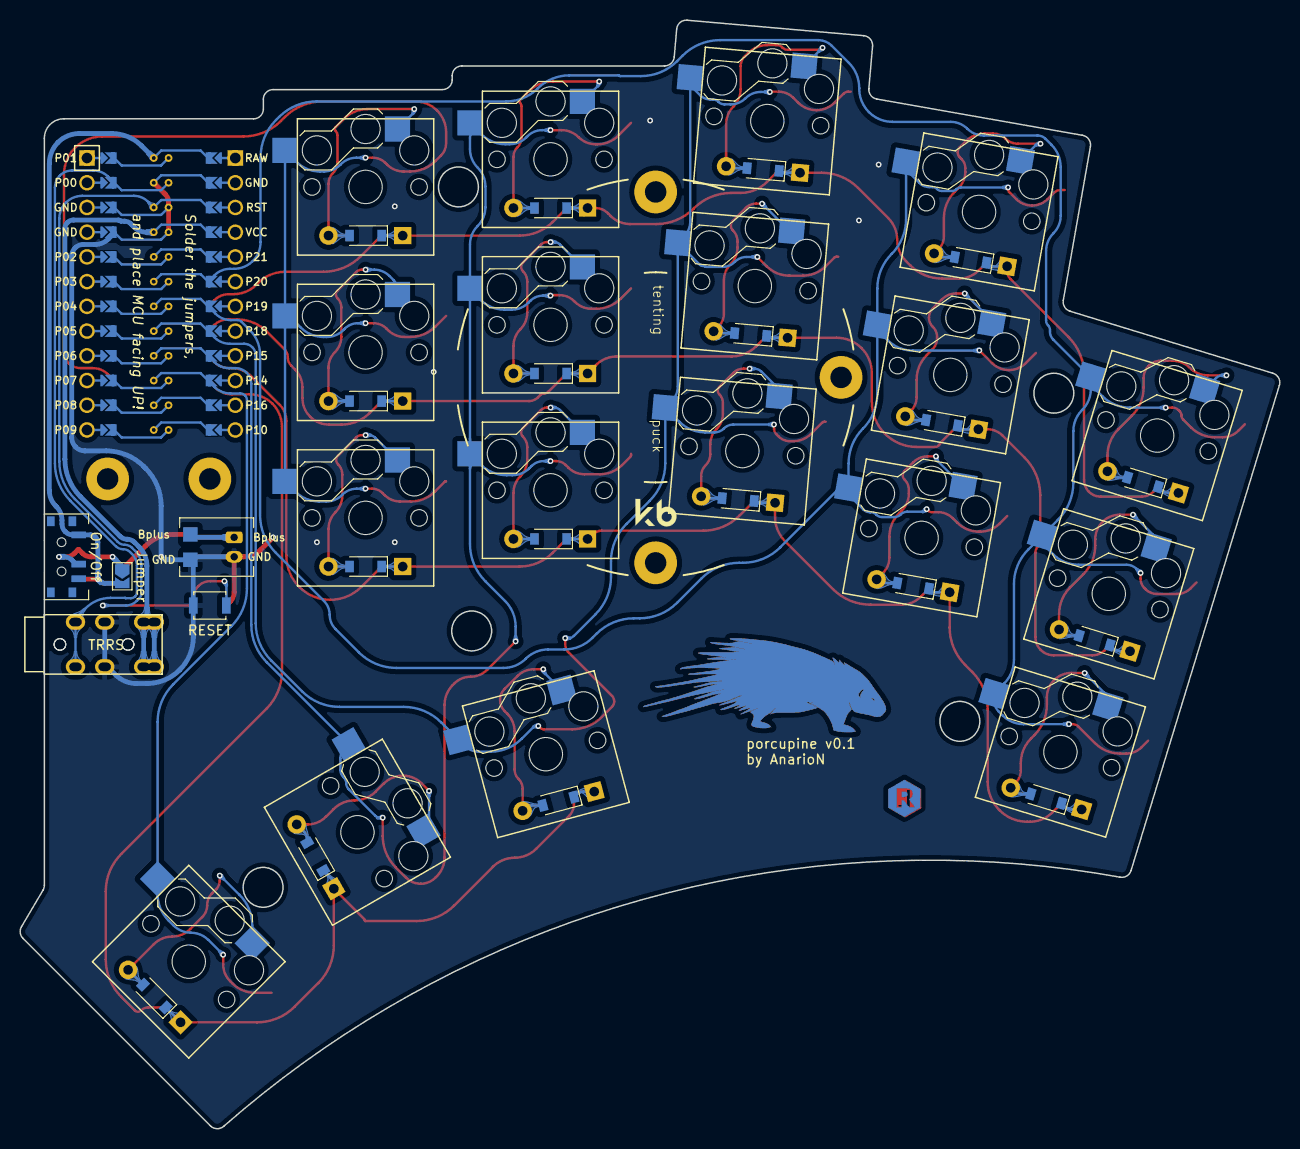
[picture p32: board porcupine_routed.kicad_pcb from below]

Board: 2 copper layers, 129.4 x 113.9 mm, 54 parts (5 on the bottom side), 33 nets.

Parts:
D1, D2, D3, D4, D5, D6, D7, D8, D9, D10, D11, D12, D13, D14, D15, D16, D17, D18: D_SOD-123; SOD-123
J1, J2: Jumper; SolderJumper-2_P1.3mm_Open_TrianglePad1.0x1.5mm
LOGO_B: Porcupine Logo
LOGO_F: Porcupine Logo
MCU1: ProMicro
PAD1, PAD2: SMDPad
S1, S2, S3, S4, S5, S6, S7, S8, S9, S10, S11, S12, S13, S14, S15, S16, S17, S18: PG1350
Side_B: Side Indicator
Side_F: Side Indicator
TRRS_B: AudioJack4; TRRS-PJ-320A-dual
TRRS_F: AudioJack4; TRRS-PJ-320A-dual
_2: bat2p0
_3: SW_SPDT_PCM12
_4_B, _4_F: SW_Push; SW_SPST_B3U-1000P
_9: Tenting Puck
_73, _74: hole; Through Hole

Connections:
Bplus: J1.1, J2.1, PAD1.1, _2.1, _3.2
GND: MCU1.2, MCU1.21, MCU1.22, PAD2.1, TRRS_B.R1, _2.2, _4_B.2
P0: MCU1.23, TRRS_B.R2
P4: D3.1, D3.2, D6.1, D6.2, D9.1, D9.2, D12.1, D12.2, D15.1, D15.2, MCU1.18
P5: D2.1, D2.2, D5.1, D5.2, D8.1, D8.2, D11.1, D11.2, D14.1, D14.2, MCU1.17
P6: D1.1, D1.2, D4.1, D4.2, D7.1, D7.2, D10.1, D10.2, D13.1, D13.2, MCU1.16
P7: D16.1, D16.2, D17.1, D17.2, D18.1, D18.2, MCU1.15
P14: MCU1.10, S13.2, S14.2, S15.2, S18.2
P15: MCU1.9, S10.2, S11.2, S12.2, S17.2
P18: MCU1.8, S7.2, S8.2, S9.2, S16.2
P19: MCU1.7, S4.2, S5.2, S6.2
P20: MCU1.6, S1.2, S2.2, S3.2
RAW: J1.2, J2.2, MCU1.1, _3.1
RST: MCU1.3, _4_B.1
VCC: MCU1.4, TRRS_B.S, TRRS_B.T
far_thumb: D18.1, D18.2, S18.1
home_thumb: D17.1, D17.2, S17.1
index_bottom: D10.1, D10.2, S10.1
index_home: D11.1, D11.2, S11.1
index_top: D12.1, D12.2, S12.1
inner_bottom: D13.1, D13.2, S13.1
inner_home: D14.1, D14.2, S14.1
inner_top: D15.1, D15.2, S15.1
middle_bottom: D7.1, D7.2, S7.1
middle_home: D8.1, D8.2, S8.1
middle_top: D9.1, D9.2, S9.1
near_thumb: D16.1, D16.2, S16.1
pinky_bottom: D1.1, D1.2, S1.1
pinky_home: D2.1, D2.2, S2.1
pinky_top: D3.1, D3.2, S3.1
ring_bottom: D4.1, D4.2, S4.1
ring_home: D5.1, D5.2, S5.1
ring_top: D6.1, D6.2, S6.1

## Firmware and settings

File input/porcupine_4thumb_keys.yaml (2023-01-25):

meta:
  version: "v0.0.1"
  author: "Anarion"
units:
  kx: cx
  ky: cy
  px: 2
  py: 2
  $default_width: cx
  $default_height: cy
points:
  key:
    padding: ky
  zones:
    matrix:
      anchor:
        shift: [180, -150]
      columns:
        pinky:
          key:
            stagger: 0 ky
            spread: 18
            splay: 17
            origin: [0, -ky]
            column_net: P20
          rows:
            top:
              bind: [0.1, 0.5 kx, 0.1, 0.5]
            home:
              bind: [0.1, 0.5 kx, 0.1, 0.5]
            bottom:
              bind: [0.5, 0.5, 15, 0.5]
        ring:
          key:
            spread: 18
            stagger: ky
            splay: -7
            origin: [0, -ky]
            column_net: P19
          rows:
            top:
              bind: [0.1, 0.5 kx, 0.1, 0.1]
            home:
              bind: [0.1, 0.5 kx, 0.1, 0.1]
            bottom:
              bind: [0.5, 0.5 kx, 35, 0.1]
        middle:
          key:
            spread: 18
            stagger: ky/3
            splay: -5
            origin: [0, -ky]
            column_net: P18
            shift: [0.2, 0]
          rows:
            top:
              bind: [0.1, 0.1, 0.5 kx, 0.1]
            bottom:
              bind: [0.5, 0.5 kx, 35, 0.1]
        index:
          key:
            spread: 18
            stagger: -ky/3
            splay: -5
            origin: [0, -ky]
            column_net: P15
          rows:
            top:
              bind: [0.1, 0.1, 0.5 kx, 0.5 kx]
        inner:
          key:
            spread: 19
            stagger: -ky/6
            origin: [0, -ky]
            column_net: P14
      rows:
        bottom:
          row_net: P6
          tags:
            high1: false
          bind: 0.5
        home:
          row_net: P5
          tags:
            high1: false
          bind: 0.5
        top:
          row_net: P4
          tags:
            high1: false
          bind: 0.5
    thumbfan:
      anchor:
        ref: matrix_inner_bottom
        shift: [-1.3 kx, -1.3 ky]
      columns:
        inner:
          key:
            spread: 0
            splay: -5
            origin: [1 kx, -2.5 ky]
            column_net: P19
          rows:
            thumb:
              tags:
                high1: true
        near:
          key:
            column_net: P18
            spread: kx
            splay: -10
            origin: [-0.5 kx, -0.8 ky]
          rows:
            thumb:
              tags:
                high1: true
        home:
          key:
            spread: kx
            splay: -15
            rotate: 90
            origin: [-0.5 kx, -0.7 ky]
            column_net: P15
          rows:
            thumb:
              bind: [3, -2, 4, 0.1]
              tags:
                high15: true
        far:
          key:
            spread: kx
            splay: -15
            rotate: 90
            origin: [-0.5 kx, -0.9 ky]
            column_net: P14
          rows:
            thumb:
              bind: [4, -2, 0.1, 0.1]
              tags:
                high15: true
      rows:
        thumb:
          row_net: P7
          bind: [0.1, 0.1, 0.1, 0.1]
outlines:
  # board dimensions according to JLCPCB: 122.28 mm x 101.05 mm
  raw:
    - what: rectangle
      size: [kx + px, ky + py]
      corner: px
      where: "high1"
      bound: true
    - what: rectangle
      size: [1.5kx + px, 1ky + py]
      corner: px
      where: "high15"
      bound: false
  raw_top_plate:
    - what: rectangle
      size: [kx + px, ky + py]
      corner: px
      where: "high1"
      bound: true
    - what: rectangle
      size: [kx + px, ky + py]
      corner: px
      where: "high15"
      bound: true
  thumbfan_glue:
    - what: polygon
      points:
        - ref: matrix_inner_bottom
          shift: [0.5 kx + 0.5px, 0.5 ky + 0.5 py]
        - ref: thumbfan_far_thumb
          shift: [0.75 kx + 0.5px, -0.55 ky - 0.5 py]
        - ref: thumbfan_far_thumb
          shift: [-0.75 kx - 0.5px, -0.55 ky - 0.5 py]
        - ref: thumbfan_near_thumb
          shift: [-0.5 kx + 0.5 px, -0.9 ky - 0.5 py]
        - ref: matrix_pinky_bottom
          shift: [0.5 kx - 0.5 py, -0.5 ky - 0.5 py]
        - ref: matrix_pinky_home
        - ref: matrix_inner_home
  thumbfan_glue_top_plate:
    - what: polygon
      points:
        - ref: matrix_inner_bottom
          shift: [0.5 kx + 1px, -0.7 ky + 0.5 py]
        # - ref: thumbfan_home_thumb
        #   shift: [1 kx + 0.5px, -0.5 ky + 0.5 py]
        - ref: thumbfan_far_thumb
          shift: [0.75 kx + 0.5px, -0.55 ky - 0.5 py]
        - ref: thumbfan_far_thumb
          shift: [-0.75 kx - 0.5px, -0.55 ky - 0.5 py]
        - ref: thumbfan_near_thumb
          shift: [-0.5 kx + 0.5 px, -0.9 ky - 0.5 py]
        - ref: matrix_pinky_bottom
          shift: [0.5 kx - 0.5 py, -0.5 ky - 0.5 py]
        - ref: matrix_pinky_home
        - ref: matrix_inner_home
  controller_area:
    main:
      what: rectangle
      adjust:
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

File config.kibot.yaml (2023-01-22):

kibot:
  version: 1

preflight:
  run_erc: false
  update_xml: false
  run_drc: true
  check_zone_fills: true
  ignore_unconnected: true

global:
  filters:
  - number: 1007
  - number: 1015
  - number: 58
  # solder_mask_color: black
  # silk_screen_color: white
  # pcb_finish: ENIG
  # aliases_for_3d_models:
  # - name: Promicro
  #   value: "../../../3dmodels/ergogen/ProMicro.stp"
  environment:
    third_party: "../../../"
    models_3d: "../../../3dmodels/ergogen/"
  field_3D_model: "model"


# filters:
# - name: only_jlc_parts
#   comment: Only parts with JLC (LCSC) code
#   type: generic
#   include_only:
#   - column: LCSC#
#     regex: ^C\d+

# variants:
# - name: place_holder
#   comment: Just a place holder for pre_transform filters
#   type: kicost
#   pre_transform:
#   - _kicost_rename
#   - _rot_footprint

outputs:
# - name: basic_boardview
#   comment: Board View export
#   type: boardview
#   dir: Assembly
# - name: basic_dxf
#   comment: Individual layers in DXF format
#   type: dxf
#   dir: Individual_Layers/DXF
#   layers:
#   - layer: F.Cu
#     suffix: F_Cu
#     description: Front copper
#   - layer: B.Cu
#     suffix: B_Cu
#     description: Bottom copper
#   - layer: B.Paste
#     suffix: B_Paste
#     description: Bottom solder paste
#   - layer: F.Paste
#     suffix: F_Paste
#     description: Front solder paste
#   - layer: B.Silkscreen
#     suffix: B_Silkscreen
#     description: Bottom silkscreen (artwork)
#   - layer: F.Silkscreen
#     suffix: F_Silkscreen
#     description: Front silkscreen (artwork)
#   - layer: B.Mask
#     suffix: B_Mask
#     description: Bottom soldermask (negative)
#   - layer: F.Mask
#     suffix: F_Mask
#     description: Front soldermask (negative)
#   - layer: User.Drawings
#     suffix: User_Drawings
#     description: User drawings
#   - layer: User.Comments
#     suffix: User_Comments
#     description: User comments
#   - layer: User.Eco1
#     suffix: User_Eco1
#     description: For user usage 1
#   - layer: User.Eco2
#     suffix: User_Eco2
#     description: For user usage 2
#   - layer: Edge.Cuts
#     suffix: Edge_Cuts
#     description: Board shape
#   - layer: B.Courtyard
#     suffix: B_Courtyard
#     description: Bottom courtyard area
#   - layer: F.Courtyard
#     suffix: F_Courtyard
#     description: Front courtyard area
#   - layer: B.Fab
#     suffix: B_Fab
#     description: Bottom documentation
#   - layer: F.Fab
#     suffix: F_Fab
#     description: Front documentation
# - name: basic_excellon
#   comment: Drill files in EXCELLON format
#   type: excellon
#   dir: Gerbers_and_Drill
#   options:
#     map: pdf
# - name: basic_gencad
#   comment: PCB in GenCAD format
#   type: gencad
#   dir: Export
# - name: basic_gerb_drill
#   comment: Drill files in GERB_DRILL format
#   type: gerb_drill
#   dir: Gerbers_and_Drill
#   options:
#     map: gerber
- name: gerber_modern
  comment: Gerbers in modern format, recommended by the standard
  type: gerber
  dir: Gerbers_and_Drill
  layers:
  - layer: F.Cu
    suffix: F_Cu
    description: Front copper
  - layer: B.Cu
    suffix: B_Cu
    description: Bottom copper
  - layer: B.Paste
    suffix: B_Paste
    description: Bottom solder paste
  - layer: F.Paste
    suffix: F_Paste
    description: Front solder paste
  - layer: B.Silkscreen
    suffix: B_Silkscreen
    description: Bottom silkscreen (artwork)
  - layer: F.Silkscreen
    suffix: F_Silkscreen
    description: Front silkscreen (artwork)
  - layer: B.Mask
    suffix: B_Mask
    description: Bottom soldermask (negative)
  - layer: F.Mask
    suffix: F_Mask
    description: Front soldermask (negative)
  - layer: User.Drawings
    suffix: User_Drawings
    description: User drawings
  - layer: User.Comments
    suffix: User_Comments
    description: User comments
  - layer: User.Eco1
    suffix: User_Eco1
    description: For user usage 1
  - layer: User.Eco2
    suffix: User_Eco2
    description: For user usage 2
  - layer: Edge.Cuts
    suffix: Edge_Cuts
    description: Board shape
  - layer: B.Courtyard
    suffix: B_Courtyard
    description: Bottom courtyard area
  - layer: F.Courtyard
    suffix: F_Courtyard
    description: Front courtyard area
  - layer: B.Fab
    suffix: B_Fab
    description: Bottom documentation
  - layer: F.Fab
    suffix: F_Fab
    description: Front documentation
- name: JLCPCB_gerbers
  comment: Gerbers compatible with JLCPCB
  type: gerber
  dir: Manufacturers/JLCPCB
  options:
    exclude_edge_layer: true
    exclude_pads_from_silkscreen: true
    plot_sheet_reference: false
    plot_footprint_refs: true
    plot_footprint_values: false
    force_plot_invisible_refs_vals: false
    tent_vias: true
    use_protel_extensions: true
    create_gerber_job_file: false
    disable_aperture_macros: true
    gerber_precision: 4.6
    use_gerber_x2_attributes: false
    use_gerber_net_attributes: false
    line_width: 0.1
    subtract_mask_from_silk: true
    inner_extension_pattern: .g%n
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

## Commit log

2023-01-22 Update input and add manually routed boards
    [porcupine.kicad_pcb, porcupine_4thumb_keys.kicad_pcb, porcupine_4thumb_keys_routed.kicad_pcb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]
2023-01-25 Update 6x3 variant
    * Removed unnecessary P19 via
    * Fix outer column stagger
    * Fix P19 matrix ring bottom via
    * Resized GND zones
    [porcupine_6x3.kicad_pcb, porcupine_6x3_bottom_plate.kicad_pcb, porcupine_6x3_top_plate.kicad_pcb]
2023-01-25 Add new logo
    [porcupine.kicad_pcb, porcupine_4thumb_keys.kicad_pcb, porcupine_6x3.kicad_pcb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]
2023-02-28 ✏️ Fix typo in README
2023-03-12 🚨 Fix markdown lint in README
2023-03-12 🚧 Added pictures of prototype boards
2023-03-12 🚧 Added link to QMK firmware/keymaps
2023-05-13 🚀 Confirmed working with QMK
2024-08-13 👷 Added a build guide

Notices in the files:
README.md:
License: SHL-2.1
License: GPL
